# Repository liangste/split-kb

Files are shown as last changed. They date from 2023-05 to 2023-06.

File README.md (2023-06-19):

# split-kb

This repo contains the hardware design files for a 105 key QMK/VIA enabled split keyboard. The design is inspired by [Keebio Sinc](https://keeb.io/collections/sinc) and [Split111](https://geekhack.org/index.php?topic=103449.0). Unlike Sinc, this keyboard contains a Southpaw numpad, and unlike Split111, the design of this keyboard is open-sourced.

The PCB is designed using KiCAD. Case files for a stacked acrylic case is designed using Shapr3D. You can find the KiCAD project in this `root` directory, DXF drawing files under `case design/v1`, and layout and VIA files in the `layout` directory.

My QMK repo's [split-kb](https://github.com/liangste/qmk_firmware/tree/split-kb) branch contains all the configuration files necessary to run QMK and VIA. This repo only contains hardware designs.

_________________

Finished keyboard with purple top layer, clear mid layers, and wrist rests made with Red Oak hardwood (stained with linseed oil).

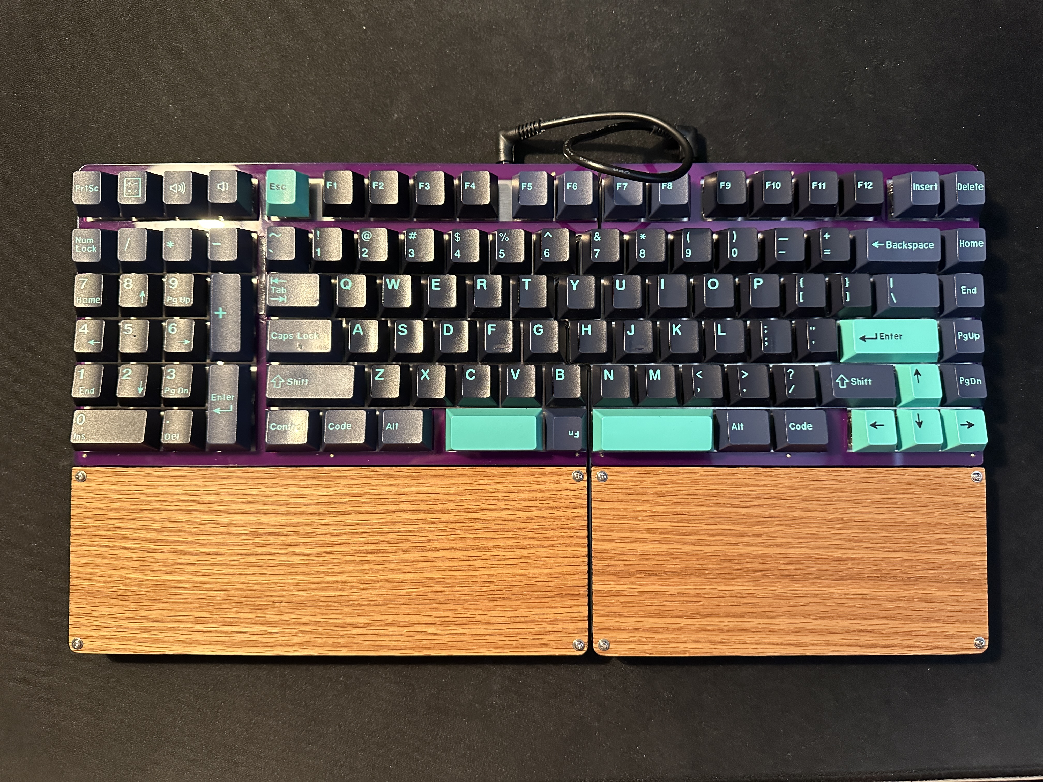
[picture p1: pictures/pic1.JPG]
top


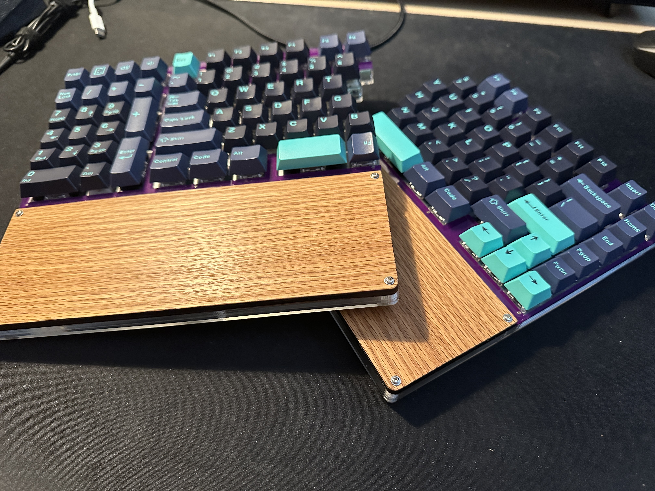
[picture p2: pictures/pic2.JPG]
split


Bottom layer showcasing a Elite-PI microcontroller and a TRRS jack for serial connection between the two halves.

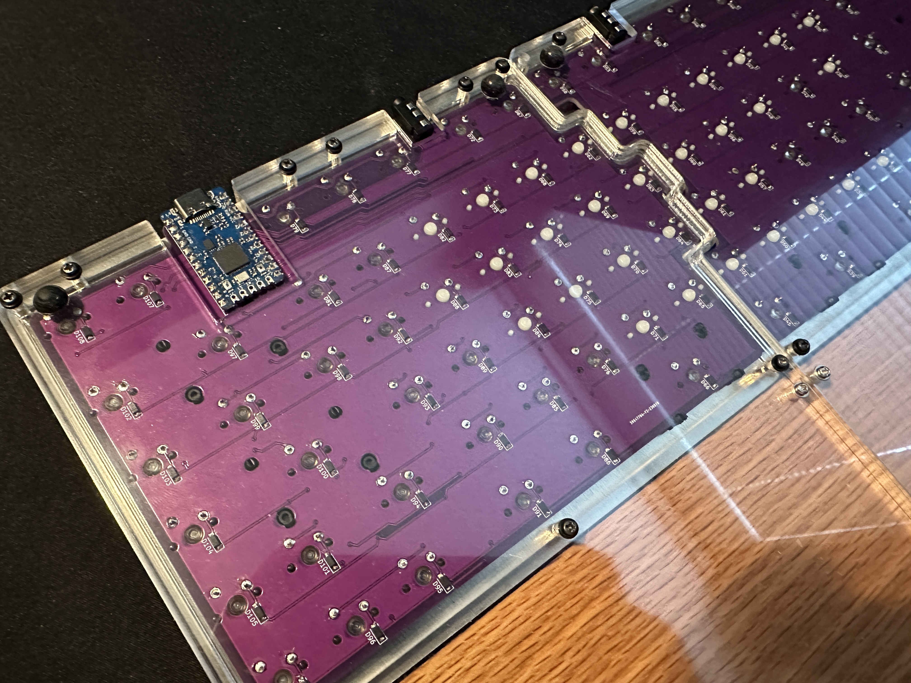
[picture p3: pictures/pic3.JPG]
bottom


A snapshot of the PCB design on KiCAD.

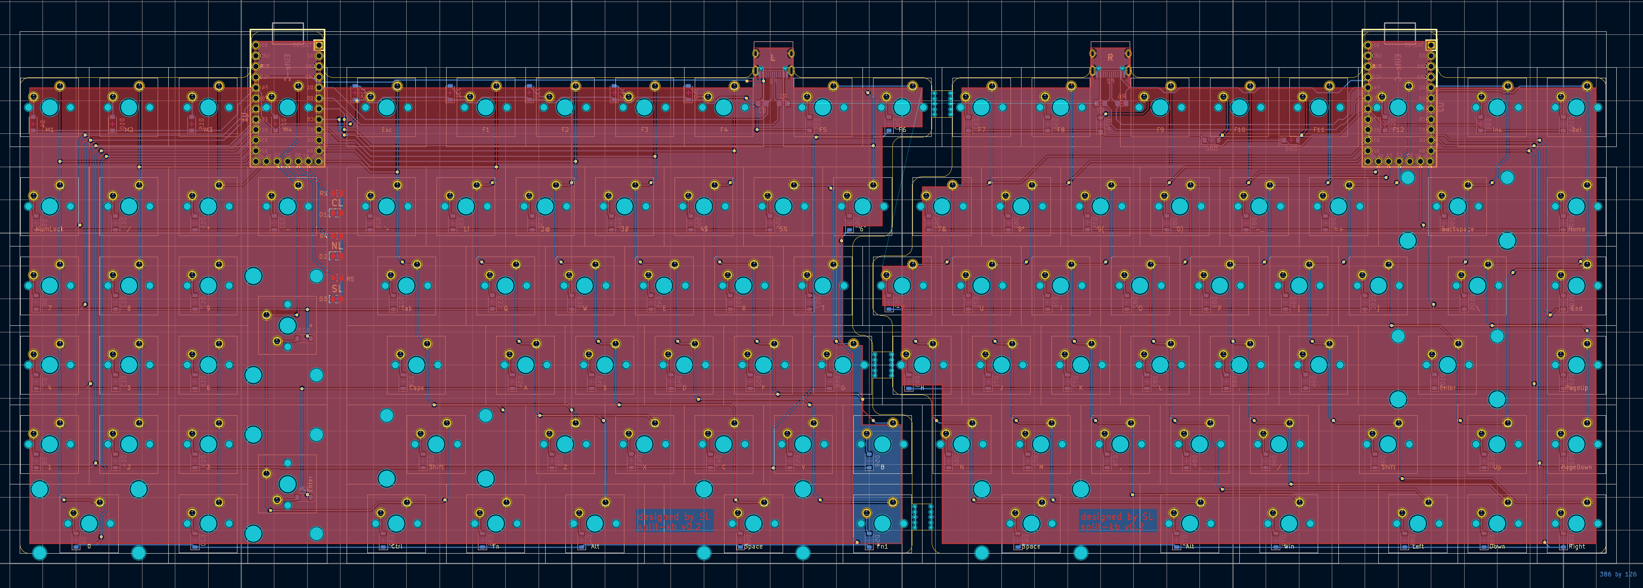
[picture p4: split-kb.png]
pcb


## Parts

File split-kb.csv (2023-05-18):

# | Reference | Qty | Value | Footprint | DNP
1 | D1, D2, D3 | 3 | LED | LED_SMD:LED_0805_2012Metric_Pad1.15x1.40mm_HandSolder
2 | D4, D5, D6, D7, D8, D9, D10, D11, D12, D13, D14, D15, D16, D17, D18, D19, D20, D21, D22, D23, D24, D25, D26, D27, D28, D29, D30, D31, D32, D33, D34, D35, D36, D37, D38, D39, D40, D41, D42, D43, D44, D45, D46, D47, D48, D49, D50, D51, D52, D53, D54, D55, D56, D57, D58, D59, D60, D61, D62, D63, D64, D65, D66, D67, D68, D69, D70, D71, D72, D73, D74, D75, D76, D77, D78, D79, D80, D81, D82, D83, D84, D85, D86, D87, D88, D89, D90, D91, D92, D93, D94, D95, D96, D97, D98, D99, D100, D101, D102, D103, D104, D105, D106, D107, D108 | 105 | D_Small | Diode_SMD:D_SOD-123
3 | MX1 | 1 | M1 | custom-footprints:Custom_SW_Cherry_MX_1.00u_PCB
4 | MX2 | 1 | NumLock | custom-footprints:Custom_SW_Cherry_MX_1.00u_PCB
5 | MX3 | 1 | 7 | custom-footprints:Custom_SW_Cherry_MX_1.00u_PCB
6 | MX4 | 1 | 4 | custom-footprints:Custom_SW_Cherry_MX_1.00u_PCB
7 | MX5 | 1 | 1 | custom-footprints:Custom_SW_Cherry_MX_1.00u_PCB
8 | MX6 | 1 | 0 | custom-footprints:Custom_SW_Cherry_MX_2.00u_PCB_stabflip
9 | MX7 | 1 | M2 | custom-footprints:Custom_SW_Cherry_MX_1.00u_PCB
10 | MX8, MX87 | 2 | / | custom-footprints:Custom_SW_Cherry_MX_1.00u_PCB
11 | MX9 | 1 | 8 | custom-footprints:Custom_SW_Cherry_MX_1.00u_PCB
12 | MX10 | 1 | 5 | custom-footprints:Custom_SW_Cherry_MX_1.00u_PCB
13 | MX11 | 1 | 2 | custom-footprints:Custom_SW_Cherry_MX_1.00u_PCB
14 | MX12 | 1 | M3 | custom-footprints:Custom_SW_Cherry_MX_1.00u_PCB
15 | MX13 | 1 | * | custom-footprints:Custom_SW_Cherry_MX_1.00u_PCB
16 | MX14 | 1 | 9 | custom-footprints:Custom_SW_Cherry_MX_1.00u_PCB
17 | MX15 | 1 | 6 | custom-footprints:Custom_SW_Cherry_MX_1.00u_PCB
18 | MX16 | 1 | 3 | custom-footprints:Custom_SW_Cherry_MX_1.00u_PCB
19 | MX17, MX81 | 2 | . | custom-footprints:Custom_SW_Cherry_MX_1.00u_PCB
20 | MX18 | 1 | M4 | custom-footprints:Custom_SW_Cherry_MX_1.00u_PCB
21 | MX19 | 1 | - | custom-footprints:Custom_SW_Cherry_MX_1.00u_PCB
22 | MX20 | 1 | + | custom-footprints:Custom_SW_Cherry_MX_2.00u_PCB_stabflip
23 | MX21 | 1 | Enter | custom-footprints:Custom_SW_Cherry_MX_2.00u_PCB_stabflip
24 | MX22 | 1 | Esc | custom-footprints:Custom_SW_Cherry_MX_1.00u_PCB
25 | MX23 | 1 | `~ | custom-footprints:Custom_SW_Cherry_MX_1.00u_PCB
26 | MX24 | 1 | Tab | custom-footprints:Custom_SW_Cherry_MX_1.50u_PCB
27 | MX25 | 1 | Caps | custom-footprints:Custom_SW_Cherry_MX_1.75u_PCB
28 | MX26 | 1 | Shift | custom-footprints:Custom_SW_Cherry_MX_2.25u_PCB
29 | MX27 | 1 | Ctrl | custom-footprints:Custom_SW_Cherry_MX_1.25u_PCB
30 | MX28 | 1 | F1 | custom-footprints:Custom_SW_Cherry_MX_1.00u_PCB
31 | MX29 | 1 | 1! | custom-footprints:Custom_SW_Cherry_MX_1.00u_PCB
32 | MX30 | 1 | Q | custom-footprints:Custom_SW_Cherry_MX_1.00u_PCB
33 | MX31 | 1 | A | custom-footprints:Custom_SW_Cherry_MX_1.00u_PCB
34 | MX32 | 1 | Z | custom-footprints:Custom_SW_Cherry_MX_1.00u_PCB
35 | MX33 | 1 | Fn | custom-footprints:Custom_SW_Cherry_MX_1.25u_PCB
36 | MX34 | 1 | F2 | custom-footprints:Custom_SW_Cherry_MX_1.00u_PCB
37 | MX35 | 1 | 2@ | custom-footprints:Custom_SW_Cherry_MX_1.00u_PCB
38 | MX36 | 1 | W | custom-footprints:Custom_SW_Cherry_MX_1.00u_PCB
39 | MX37 | 1 | S | custom-footprints:Custom_SW_Cherry_MX_1.00u_PCB
40 | MX38 | 1 | X | custom-footprints:Custom_SW_Cherry_MX_1.00u_PCB
41 | MX39, MX70 | 2 | Alt | custom-footprints:Custom_SW_Cherry_MX_1.25u_PCB
42 | MX40 | 1 | F3 | custom-footprints:Custom_SW_Cherry_MX_1.00u_PCB
43 | MX41 | 1 | 3# | custom-footprints:Custom_SW_Cherry_MX_1.00u_PCB
44 | MX42 | 1 | E | custom-footprints:Custom_SW_Cherry_MX_1.00u_PCB
45 | MX43 | 1 | D | custom-footprints:Custom_SW_Cherry_MX_1.00u_PCB
46 | MX44 | 1 | C | custom-footprints:Custom_SW_Cherry_MX_1.00u_PCB
47 | MX45 | 1 | Space | custom-footprints:Custom_SW_Cherry_MX_2.25u_PCB_stabflip
48 | MX46 | 1 | F4 | custom-footprints:Custom_SW_Cherry_MX_1.00u_PCB
49 | MX47 | 1 | 4$ | custom-footprints:Custom_SW_Cherry_MX_1.00u_PCB
50 | MX48 | 1 | R | custom-footprints:Custom_SW_Cherry_MX_1.00u_PCB
51 | MX49 | 1 | F | custom-footprints:Custom_SW_Cherry_MX_1.00u_PCB
52 | MX50 | 1 | V | custom-footprints:Custom_SW_Cherry_MX_1.00u_PCB
53 | MX51 | 1 | Fn1 | custom-footprints:Custom_SW_Cherry_MX_1.00u_PCB
54 | MX52 | 1 | F5 | custom-footprints:Custom_SW_Cherry_MX_1.00u_PCB
55 | MX53 | 1 | 5% | custom-footprints:Custom_SW_Cherry_MX_1.00u_PCB
56 | MX54 | 1 | T | custom-footprints:Custom_SW_Cherry_MX_1.00u_PCB
57 | MX55 | 1 | G | custom-footprints:Custom_SW_Cherry_MX_1.00u_PCB
58 | MX56 | 1 | B | custom-footprints:Custom_SW_Cherry_MX_1.00u_PCB
59 | MX57 | 1 | F6 | custom-footprints:Custom_SW_Cherry_MX_1.00u_PCB
60 | MX58 | 1 | 6^ | custom-footprints:Custom_SW_Cherry_MX_1.00u_PCB
61 | MX59 | 1 | F7 | custom-footprints:Custom_SW_Cherry_MX_1.00u_PCB
62 | MX60 | 1 | 7& | custom-footprints:Custom_SW_Cherry_MX_1.00u_PCB
63 | MX61 | 1 | Y | custom-footprints:Custom_SW_Cherry_MX_1.00u_PCB
64 | MX62 | 1 | H | custom-footprints:Custom_SW_Cherry_MX_1.00u_PCB
65 | MX63 | 1 | N | custom-footprints:Custom_SW_Cherry_MX_1.00u_PCB
66 | MX64 | 1 | Space | custom-footprints:Custom_SW_Cherry_MX_2.75u_PCB_stabflip
67 | MX65 | 1 | F8 | custom-footprints:Custom_SW_Cherry_MX_1.00u_PCB
68 | MX66 | 1 | 8* | custom-footprints:Custom_SW_Cherry_MX_1.00u_PCB
69 | MX67 | 1 | U | custom-footprints:Custom_SW_Cherry_MX_1.00u_PCB
70 | MX68 | 1 | J | custom-footprints:Custom_SW_Cherry_MX_1.00u_PCB
71 | MX69 | 1 | M | custom-footprints:Custom_SW_Cherry_MX_1.00u_PCB
72 | MX71 | 1 | F9 | custom-footprints:Custom_SW_Cherry_MX_1.00u_PCB
73 | MX72 | 1 | 9( | custom-footprints:Custom_SW_Cherry_MX_1.00u_PCB
74 | MX73 | 1 | I | custom-footprints:Custom_SW_Cherry_MX_1.00u_PCB
75 | MX74 | 1 | K | custom-footprints:Custom_SW_Cherry_MX_1.00u_PCB
76 | MX75 | 1 | , | custom-footprints:Custom_SW_Cherry_MX_1.00u_PCB
77 | MX76 | 1 | Win | custom-footprints:Custom_SW_Cherry_MX_1.25u_PCB
78 | MX77 | 1 | F10 | custom-footprints:Custom_SW_Cherry_MX_1.00u_PCB
79 | MX78 | 1 | 0) | custom-footprints:Custom_SW_Cherry_MX_1.00u_PCB
80 | MX79 | 1 | O | custom-footprints:Custom_SW_Cherry_MX_1.00u_PCB
81 | MX80 | 1 | L | custom-footprints:Custom_SW_Cherry_MX_1.00u_PCB
82 | MX82 | 1 | Left | custom-footprints:Custom_SW_Cherry_MX_1.00u_PCB
83 | MX83 | 1 | F11 | custom-footprints:Custom_SW_Cherry_MX_1.00u_PCB
84 | MX84 | 1 | -_ | custom-footprints:Custom_SW_Cherry_MX_1.00u_PCB
85 | MX85 | 1 | P | custom-footprints:Custom_SW_Cherry_MX_1.00u_PCB
86 | MX86 | 1 | ; | custom-footprints:Custom_SW_Cherry_MX_1.00u_PCB
87 | MX88 | 1 | Down | custom-footprints:Custom_SW_Cherry_MX_1.00u_PCB
88 | MX89 | 1 | F12 | custom-footprints:Custom_SW_Cherry_MX_1.00u_PCB
89 | MX90 | 1 | =+ | custom-footprints:Custom_SW_Cherry_MX_1.00u_PCB
90 | MX91 | 1 | [ | custom-footprints:Custom_SW_Cherry_MX_1.00u_PCB
91 | MX92 | 1 | ' | custom-footprints:Custom_SW_Cherry_MX_1.00u_PCB
92 | MX93 | 1 | Shift | custom-footprints:Custom_SW_Cherry_MX_1.75u_PCB
93 | MX94 | 1 | Right | custom-footprints:Custom_SW_Cherry_MX_1.00u_PCB
94 | MX95 | 1 | Ins | custom-footprints:Custom_SW_Cherry_MX_1.00u_PCB
95 | MX96 | 1 | Backspace | custom-footprints:Custom_SW_Cherry_MX_2.00u_PCB
96 | MX97 | 1 | ] | custom-footprints:Custom_SW_Cherry_MX_1.00u_PCB
97 | MX98 | 1 | Enter | custom-footprints:Custom_SW_Cherry_MX_2.25u_PCB
98 | MX99 | 1 | Up | custom-footprints:Custom_SW_Cherry_MX_1.00u_PCB
99 | MX100 | 1 | Del | custom-footprints:Custom_SW_Cherry_MX_1.00u_PCB
100 | MX101 | 1 | Home | custom-footprints:Custom_SW_Cherry_MX_1.00u_PCB
101 | MX102 | 1 | \ | custom-footprints:Custom_SW_Cherry_MX_1.50u_PCB
102 | MX103 | 1 | PageUp | custom-footprints:Custom_SW_Cherry_MX_1.00u_PCB
103 | MX104 | 1 | PageDown | custom-footprints:Custom_SW_Cherry_MX_1.00u_PCB
104 | MX105 | 1 | End | custom-footprints:Custom_SW_Cherry_MX_1.00u_PCB
105 | P1, P2 | 2 | I2C/USB-C | Connector_USB:USB_C_Receptacle_HRO_TYPE-C-31-M-12
106 | R1, R4, R5 | 3 | 2.2k | Resistor_SMD:R_0805_2012Metric_Pad1.20x1.40mm_HandSolder
107 | R2, R3, R6, R7 | 4 | 2.2K | Resistor_SMD:R_0805_2012Metric_Pad1.20x1.40mm_HandSolder
108 | U1, U2 | 2 | Elite-C | Keebio-Parts:Elite-C

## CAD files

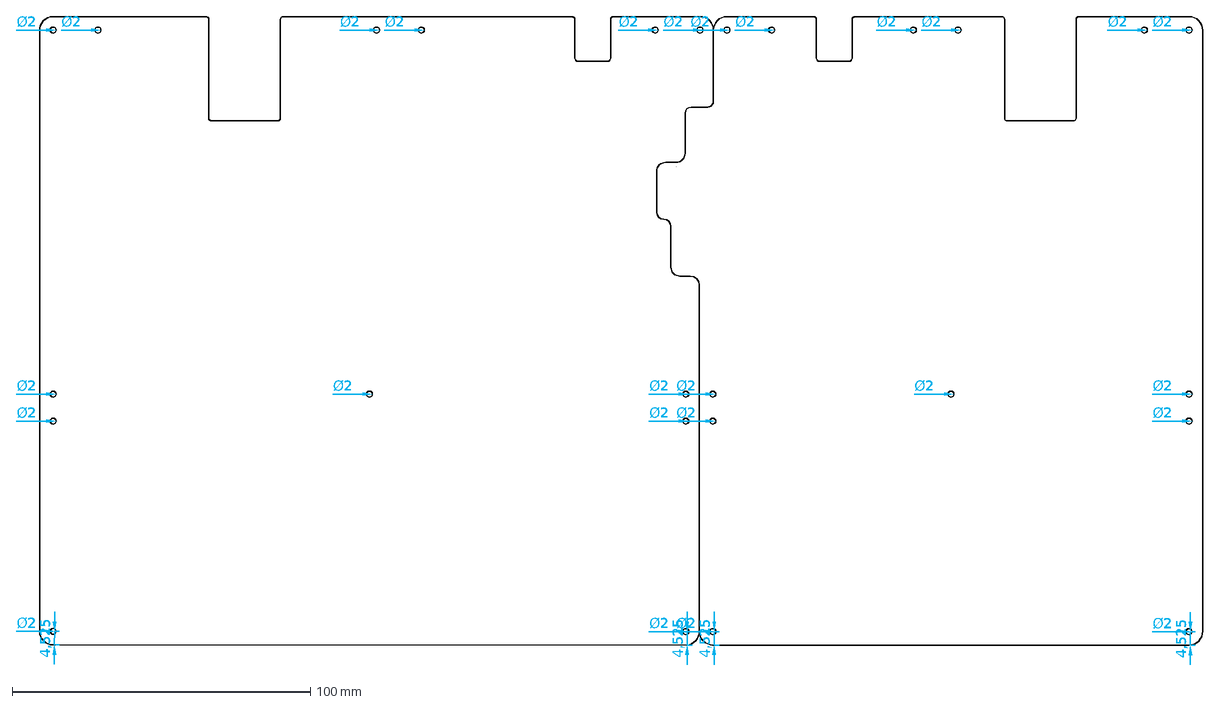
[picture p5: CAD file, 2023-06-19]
case design/v1/combined baseplates v1.dxf
4,525
Ø2

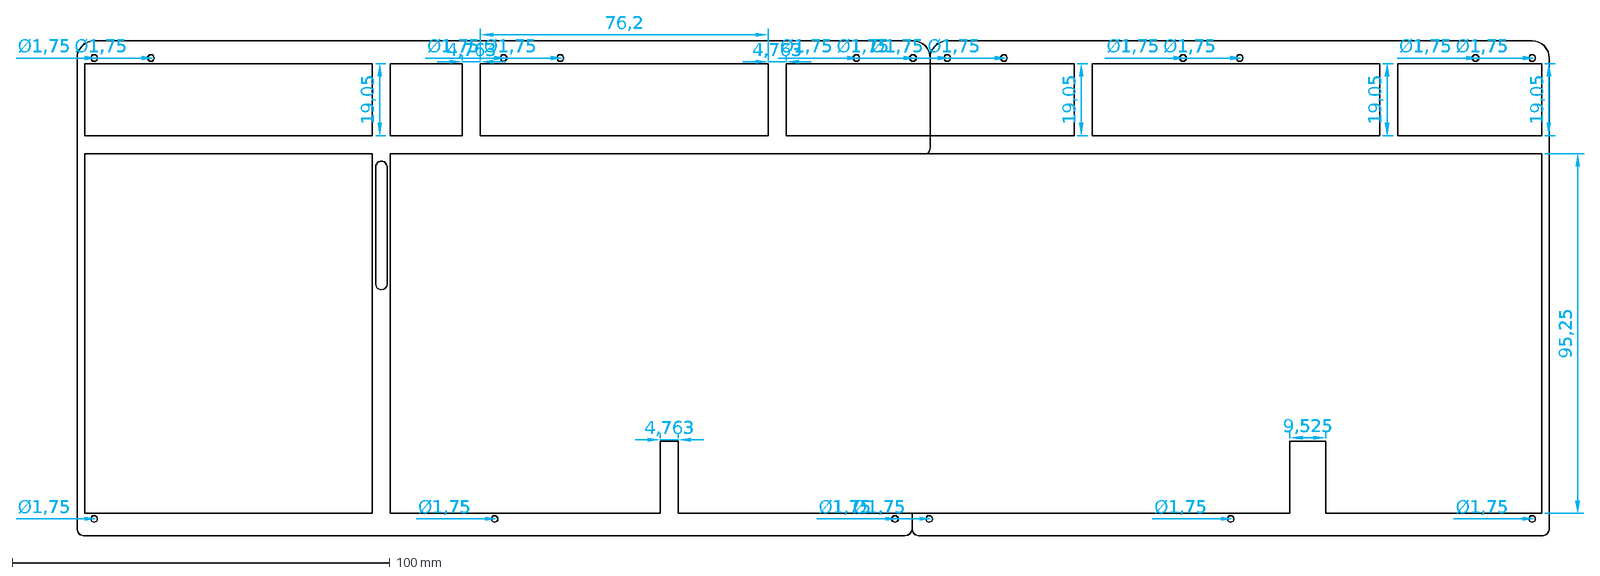
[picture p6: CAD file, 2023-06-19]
case design/v1/combined topplates v1.1.dxf
19,05
95,25
4,763
76,2
9,525
Ø1,75

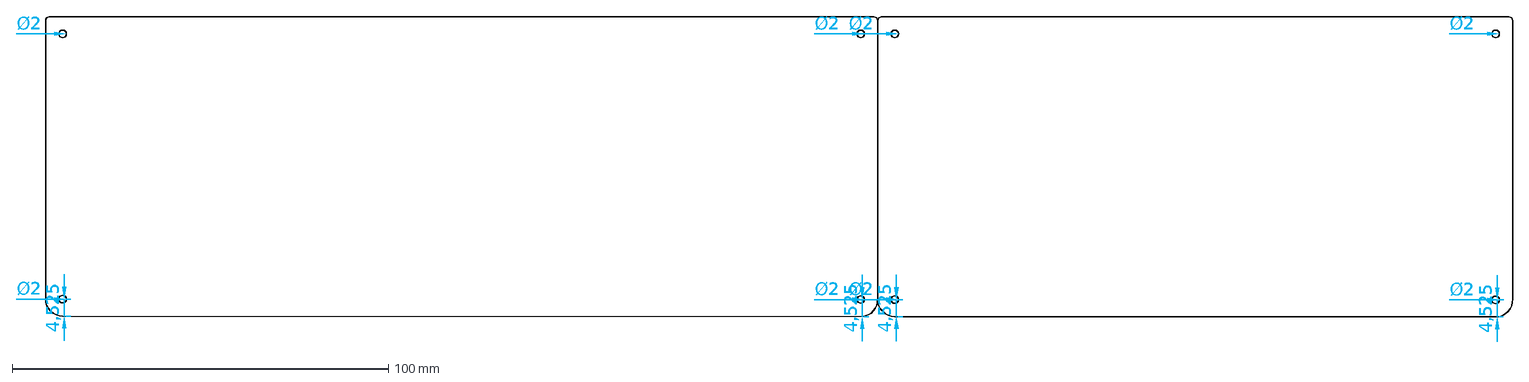
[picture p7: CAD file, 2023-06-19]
case design/v1/combined wrist rests v1.dxf
4,525
Ø2

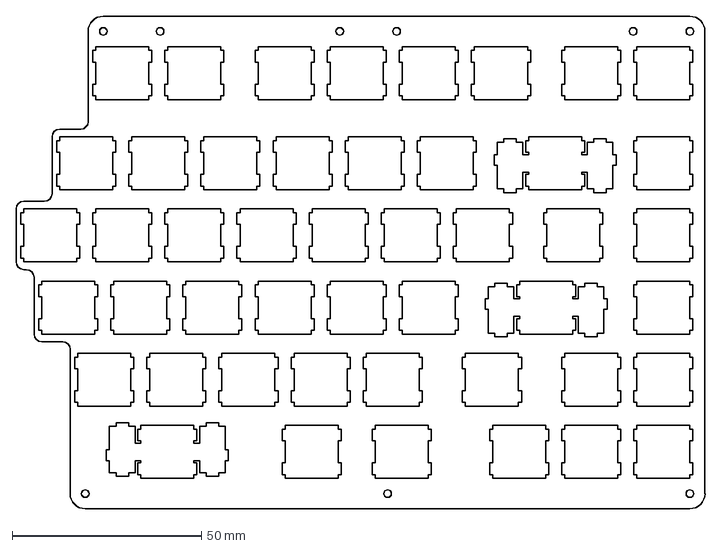
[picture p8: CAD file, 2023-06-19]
case design/v1/right switchplate v1.dxf
181.9 x 130.0 mm

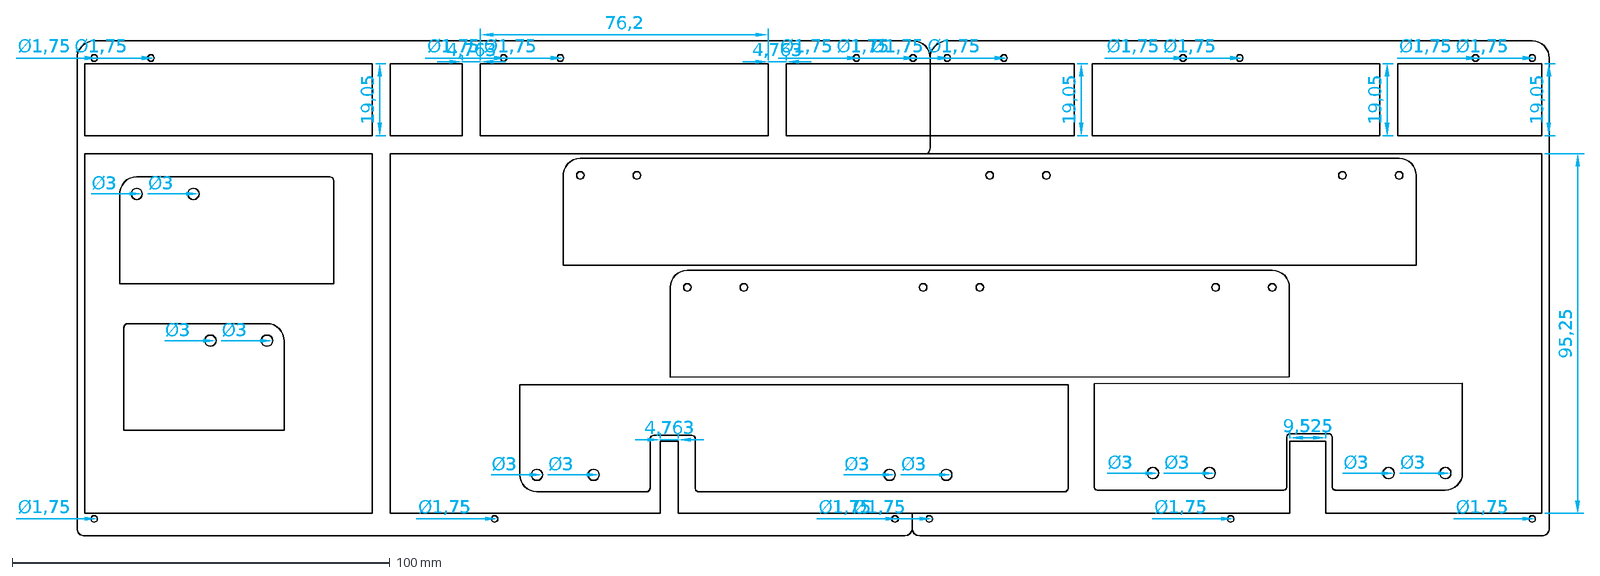
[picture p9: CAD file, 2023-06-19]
case design/v1/combined topplates v1.1 w_ feet.dxf
19,05
95,25
4,763
76,2
9,525
Ø3
Ø1,75

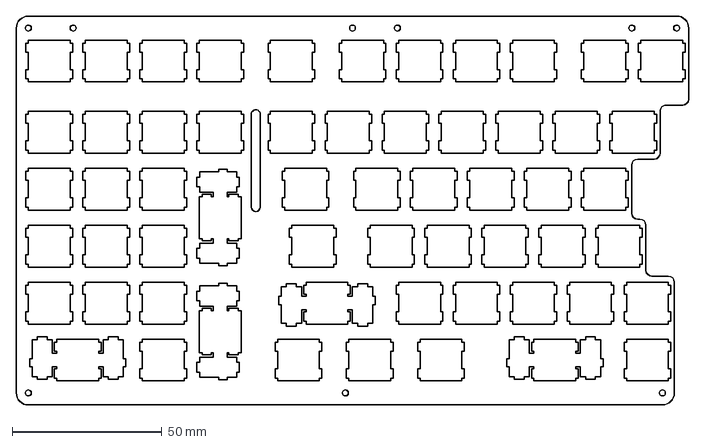
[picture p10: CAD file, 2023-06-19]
case design/v1/left switchplate v1.dxf
224.8 x 130.0 mm

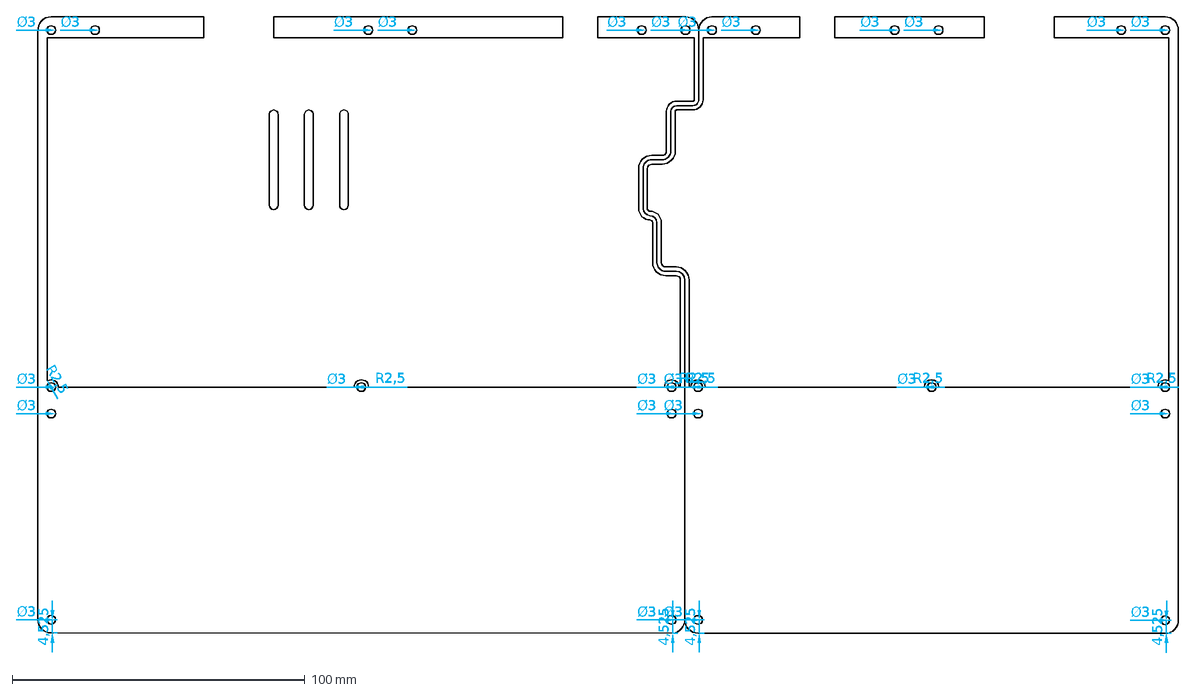
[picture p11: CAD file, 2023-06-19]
case design/v1/combined midplates v1.dxf
4,525
R2,5
Ø3

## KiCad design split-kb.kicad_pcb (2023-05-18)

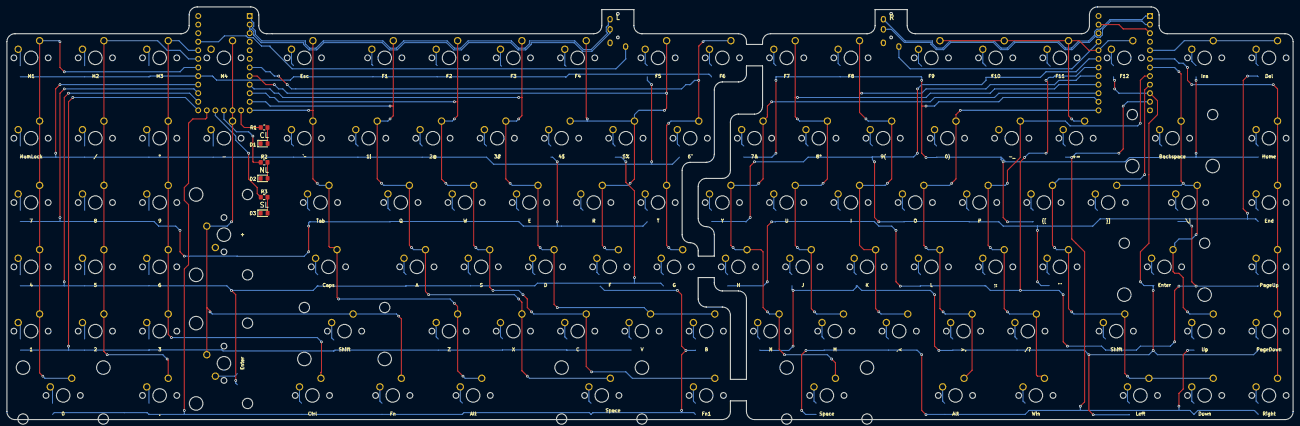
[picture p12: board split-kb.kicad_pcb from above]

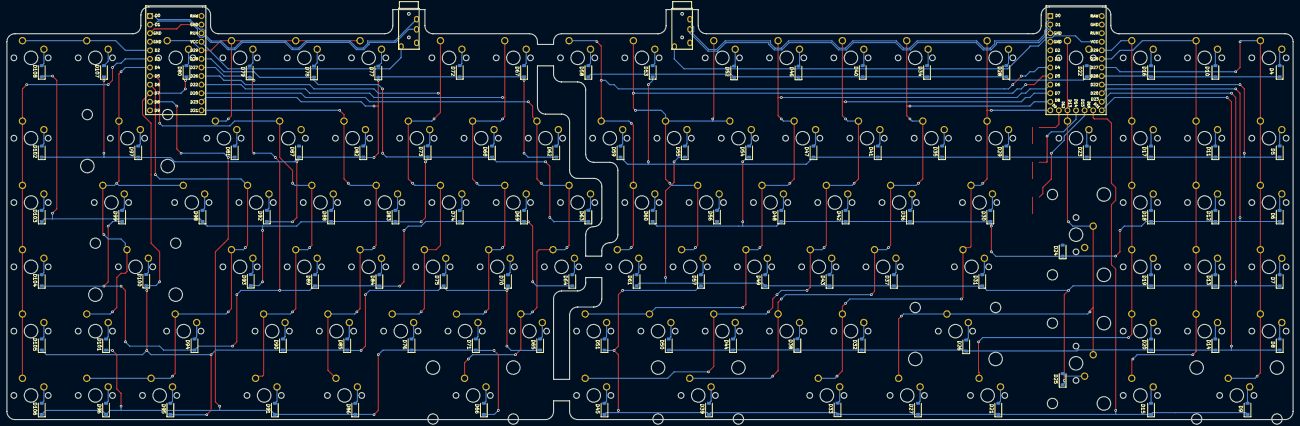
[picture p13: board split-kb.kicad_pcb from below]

Board: 2 copper layers, 381.0 x 122.2 mm, 220 parts (109 on the bottom side), 148 nets.

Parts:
D1, D2, D3: LED; LED_0805_2012Metric_Pad1.15x1.40mm_HandSolder
D4, D5, D6, D7, D8, D9, D10, D11, D12, D13, D14, D15, D16, D17, D18, D19, D20, D21, D22, D23, D24, D25, D26, D27, D28, D29, D30, D31, D32, D33, D34, D35, D36, D37, D38, D39, D40, D41, D42, D43, D44, D45, D46, D47, D48, D49, D50, D51, D52, D53, D54, D55, D56, D57, D58, D59, D60, D61, D62, D63, D64, D65, D66, D67, D68, D69, D70, D71, D72, D73, D74, D75, D76, D77, D78, D79, D80, D81, D82, D83, D84, D85, D86, D87, D88, D89, D90, D91, D92, D93, D94, D95, D96, D97, D98, D99, D100, D101, D102, D103, D104, D105, D106, D107, D108: D_Small; D_SOD-123
MX1: M1; Custom_SW_Cherry_MX_1.00u_PCB
MX2: NumLock; Custom_SW_Cherry_MX_1.00u_PCB
MX3: 7; Custom_SW_Cherry_MX_1.00u_PCB
MX4: 4; Custom_SW_Cherry_MX_1.00u_PCB
MX5: 1; Custom_SW_Cherry_MX_1.00u_PCB
MX6: 0; Custom_SW_Cherry_MX_2.00u_PCB_stabflip
MX7: M2; Custom_SW_Cherry_MX_1.00u_PCB
MX8: /; Custom_SW_Cherry_MX_1.00u_PCB
MX9: 8; Custom_SW_Cherry_MX_1.00u_PCB
MX10: 5; Custom_SW_Cherry_MX_1.00u_PCB
MX11: 2; Custom_SW_Cherry_MX_1.00u_PCB
MX12: .; Custom_SW_Cherry_MX_1.00u_PCB
MX13: M3; Custom_SW_Cherry_MX_1.00u_PCB
MX14: *; Custom_SW_Cherry_MX_1.00u_PCB
MX15: 9; Custom_SW_Cherry_MX_1.00u_PCB
MX16: 6; Custom_SW_Cherry_MX_1.00u_PCB
MX17: 3; Custom_SW_Cherry_MX_1.00u_PCB
MX18: Ctrl; Custom_SW_Cherry_MX_1.25u_PCB
MX19: M4; Custom_SW_Cherry_MX_1.00u_PCB
MX20: -; Custom_SW_Cherry_MX_1.00u_PCB
MX21: +; Custom_SW_Cherry_MX_2.00u_PCB_stabflip
MX22: Enter; Custom_SW_Cherry_MX_2.00u_PCB_stabflip
MX23: Shift; Custom_SW_Cherry_MX_2.25u_PCB
MX24: Fn; Custom_SW_Cherry_MX_1.25u_PCB
MX25: Esc; Custom_SW_Cherry_MX_1.00u_PCB
MX26: `~; Custom_SW_Cherry_MX_1.00u_PCB
MX27: Tab; Custom_SW_Cherry_MX_1.50u_PCB
MX28: Caps; Custom_SW_Cherry_MX_1.75u_PCB
MX29: Z; Custom_SW_Cherry_MX_1.00u_PCB
MX30, MX83: Alt; Custom_SW_Cherry_MX_1.25u_PCB
MX31: F1; Custom_SW_Cherry_MX_1.00u_PCB
MX32: 1!; Custom_SW_Cherry_MX_1.00u_PCB
MX33: Q; Custom_SW_Cherry_MX_1.00u_PCB
MX34: A; Custom_SW_Cherry_MX_1.00u_PCB
MX35: X; Custom_SW_Cherry_MX_1.00u_PCB
MX36: Space; Custom_SW_Cherry_MX_2.25u_PCB_stabflip
MX37: F2; Custom_SW_Cherry_MX_1.00u_PCB
MX38: 2@; Custom_SW_Cherry_MX_1.00u_PCB
MX39: W; Custom_SW_Cherry_MX_1.00u_PCB
MX40: S; Custom_SW_Cherry_MX_1.00u_PCB
MX41: C; Custom_SW_Cherry_MX_1.00u_PCB
MX42: Fn1; Custom_SW_Cherry_MX_1.00u_PCB
MX43: F3; Custom_SW_Cherry_MX_1.00u_PCB
MX44: 3#; Custom_SW_Cherry_MX_1.00u_PCB
MX45: E; Custom_SW_Cherry_MX_1.00u_PCB
MX46: D; Custom_SW_Cherry_MX_1.00u_PCB
MX47: V; Custom_SW_Cherry_MX_1.00u_PCB
MX48: B; Custom_SW_Cherry_MX_1.00u_PCB
MX49: F4; Custom_SW_Cherry_MX_1.00u_PCB
MX50: F5; Custom_SW_Cherry_MX_1.00u_PCB
MX51: 4$; Custom_SW_Cherry_MX_1.00u_PCB
MX52: 5%; Custom_SW_Cherry_MX_1.00u_PCB
MX53: R; Custom_SW_Cherry_MX_1.00u_PCB
MX54: F; Custom_SW_Cherry_MX_1.00u_PCB
MX55: F6; Custom_SW_Cherry_MX_1.00u_PCB
MX56: 6^; Custom_SW_Cherry_MX_1.00u_PCB
MX57: T; Custom_SW_Cherry_MX_1.00u_PCB
MX58: G; Custom_SW_Cherry_MX_1.00u_PCB
MX59: 7&; Custom_SW_Cherry_MX_1.00u_PCB
MX60: Y; Custom_SW_Cherry_MX_1.00u_PCB
MX61: H; Custom_SW_Cherry_MX_1.00u_PCB
MX62: N; Custom_SW_Cherry_MX_1.00u_PCB
MX63: Space; Custom_SW_Cherry_MX_2.75u_PCB_stabflip
MX64: F7; Custom_SW_Cherry_MX_1.00u_PCB
MX65: 8*; Custom_SW_Cherry_MX_1.00u_PCB
MX66: U; Custom_SW_Cherry_MX_1.00u_PCB
MX67: J; Custom_SW_Cherry_MX_1.00u_PCB
MX68: M; Custom_SW_Cherry_MX_1.00u_PCB
MX69: F8; Custom_SW_Cherry_MX_1.00u_PCB
MX70: 9(; Custom_SW_Cherry_MX_1.00u_PCB
MX71: I; Custom_SW_Cherry_MX_1.00u_PCB
MX72: K; Custom_SW_Cherry_MX_1.00u_PCB
MX73: ,<; Custom_SW_Cherry_MX_1.00u_PCB
MX74: F9; Custom_SW_Cherry_MX_1.00u_PCB
MX75: F10; Custom_SW_Cherry_MX_1.00u_PCB
MX76: F11; Custom_SW_Cherry_MX_1.00u_PCB
MX77: F12; Custom_SW_Cherry_MX_1.00u_PCB
MX78: +=; Custom_SW_Cherry_MX_1.00u_PCB
MX79: 0); Custom_SW_Cherry_MX_1.00u_PCB
MX80: O; Custom_SW_Cherry_MX_1.00u_PCB
MX81: L; Custom_SW_Cherry_MX_1.00u_PCB
MX82: >.; Custom_SW_Cherry_MX_1.00u_PCB
MX84: -_; Custom_SW_Cherry_MX_1.00u_PCB
MX85: P; Custom_SW_Cherry_MX_1.00u_PCB
MX86: ;:; Custom_SW_Cherry_MX_1.00u_PCB
MX87: /?; Custom_SW_Cherry_MX_1.00u_PCB
MX88: Win; Custom_SW_Cherry_MX_1.25u_PCB
MX89: {[; Custom_SW_Cherry_MX_1.00u_PCB
MX90: "'; Custom_SW_Cherry_MX_1.00u_PCB
MX91: Shift; Custom_SW_Cherry_MX_1.75u_PCB
MX92: Left; Custom_SW_Cherry_MX_1.00u_PCB
MX93: Down; Custom_SW_Cherry_MX_1.00u_PCB
MX94: Backspace; Custom_SW_Cherry_MX_2.00u_PCB
MX95: }]; Custom_SW_Cherry_MX_1.00u_PCB
MX96: \|; Custom_SW_Cherry_MX_1.50u_PCB
MX97: Enter; Custom_SW_Cherry_MX_2.25u_PCB
MX98: Up; Custom_SW_Cherry_MX_1.00u_PCB
MX99: Home; Custom_SW_Cherry_MX_1.00u_PCB
MX100: End; Custom_SW_Cherry_MX_1.00u_PCB
MX101: PageUp; Custom_SW_Cherry_MX_1.00u_PCB
MX102: PageDown; Custom_SW_Cherry_MX_1.00u_PCB
MX103: Right; Custom_SW_Cherry_MX_1.00u_PCB
MX104: Ins; Custom_SW_Cherry_MX_1.00u_PCB
MX105: Del; Custom_SW_Cherry_MX_1.00u_PCB
R1, R2, R3: 2.2k; R_0805_2012Metric_Pad1.20x1.40mm_HandSolder
U1, U3: TRRS; TRRS-PJ-320A
U2: Elite-PI
U4: Elite-PI; Elite-PI_24pin

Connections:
+3.3V: U1.1 (SLEEVE), U2.21 (VCC), U3.1 (SLEEVE), U4.21 (VCC)
/left_pcb/col0: MX1.1 (COL), MX2.1 (COL), MX3.1 (COL), MX4.1 (COL), MX5.1 (COL), MX6.1 (COL), U2.18 (D27)
/left_pcb/col1: MX7.1 (COL), MX8.1 (COL), MX9.1 (COL), MX10.1 (COL), MX11.1 (COL), MX12.1 (COL), U2.19 (D28)
/left_pcb/col2: MX13.1 (COL), MX14.1 (COL), MX15.1 (COL), MX16.1 (COL), MX17.1 (COL), MX18.1 (COL), U2.20 (D29)
/left_pcb/col3: MX19.1 (COL), MX20.1 (COL), MX21.1 (COL), MX22.1 (COL), MX23.1 (COL), MX24.1 (COL), U2.26 (D13)
/left_pcb/col4: MX25.1 (COL), MX26.1 (COL), MX27.1 (COL), MX28.1 (COL), MX29.1 (COL), MX30.1 (COL), U2.12 (D9)
/left_pcb/col5: MX31.1 (COL), MX32.1 (COL), MX33.1 (COL), MX34.1 (COL), MX35.1 (COL), MX36.1 (COL), U2.11 (D8)
/left_pcb/col6: MX37.1 (COL), MX38.1 (COL), MX39.1 (COL), MX40.1 (COL), MX41.1 (COL), MX42.1 (COL), U2.10 (D7)
/left_pcb/col7: MX43.1 (COL), MX44.1 (COL), MX45.1 (COL), MX46.1 (COL), MX47.1 (COL), MX48.1 (COL), U2.9 (D6)
/left_pcb/col8: MX49.1 (COL), MX50.1 (COL), MX51.1 (COL), MX52.1 (COL), MX53.1 (COL), MX54.1 (COL), U2.8 (D5)
/left_pcb/col9: MX55.1 (COL), MX56.1 (COL), MX57.1 (COL), MX58.1 (COL), U2.7 (D4)
/left_pcb/led0: R1.1, U2.25 (D12)
/left_pcb/led1: R2.1, U2.27 (D14)
/left_pcb/led2: R3.1, U2.28 (D15)
/left_pcb/row0: D4.1 (K), D10.1 (K), D16.1 (K), D22.1 (K), D28.1 (K), D34.1 (K), D40.1 (K), D46.1 (K), D52.1 (K), D58.1 (K), U2.17 (D26)
/left_pcb/row1: D5.1 (K), D11.1 (K), D17.1 (K), D23.1 (K), D29.1 (K), D35.1 (K), D41.1 (K), D47.1 (K), D53.1 (K), D59.1 (K), U2.16 (D22)
/left_pcb/row2: D6.1 (K), D12.1 (K), D18.1 (K), D24.1 (K), D30.1 (K), D36.1 (K), D42.1 (K), D48.1 (K), D54.1 (K), D60.1 (K), U2.15 (D20)
/left_pcb/row3: D7.1 (K), D13.1 (K), D19.1 (K), D25.1 (K), D31.1 (K), D37.1 (K), D43.1 (K), D49.1 (K), D55.1 (K), D61.1 (K), U2.14 (D23)
/left_pcb/row4: D8.1 (K), D14.1 (K), D20.1 (K), D26.1 (K), D32.1 (K), D38.1 (K), D44.1 (K), D50.1 (K), D56.1 (K), U2.13 (D21)
/left_pcb/row5: D9.1 (K), D15.1 (K), D21.1 (K), D27.1 (K), D33.1 (K), D39.1 (K), D45.1 (K), D51.1 (K), D57.1 (K), U2.29 (D16)
/left_pcb/serial+: U1.4 (RING2), U2.1 (D0)
/left_pcb/serial-: U1.3 (RING1), U2.2 (D1)
/right_pcb/col0: MX59.1 (COL), MX60.1 (COL), MX61.1 (COL), MX62.1 (COL), MX63.1 (COL), U4.15 (D20)
/right_pcb/col1: MX64.1 (COL), MX65.1 (COL), MX66.1 (COL), MX67.1 (COL), MX68.1 (COL), U4.16 (D22)
/right_pcb/col2: MX69.1 (COL), MX70.1 (COL), MX71.1 (COL), MX72.1 (COL), MX73.1 (COL), U4.17 (D26)
/right_pcb/col3: MX74.1 (COL), MX75.1 (COL), MX76.1 (COL), MX77.1 (COL), MX78.1 (COL), U4.20 (D29)
/right_pcb/col4: MX79.1 (COL), MX80.1 (COL), MX81.1 (COL), MX82.1 (COL), MX83.1 (COL), U4.13 (D21)
/right_pcb/col5: MX84.1 (COL), MX85.1 (COL), MX86.1 (COL), MX87.1 (COL), MX88.1 (COL), U4.8 (D5)
/right_pcb/col6: MX89.1 (COL), MX90.1 (COL), MX91.1 (COL), MX92.1 (COL), MX93.1 (COL), U4.9 (D6)
/right_pcb/col7: MX94.1 (COL), MX95.1 (COL), MX96.1 (COL), MX97.1 (COL), MX98.1 (COL), U4.7 (D4)
/right_pcb/col8: MX99.1 (COL), MX100.1 (COL), MX101.1 (COL), MX102.1 (COL), MX103.1 (COL), U4.6 (D3)
/right_pcb/col9: MX104.1 (COL), MX105.1 (COL), U4.5 (D2)
/right_pcb/row0: D62.1 (K), D67.1 (K), D72.1 (K), D77.1 (K), D82.1 (K), D87.1 (K), D92.1 (K), D97.1 (K), D102.1 (K), D107.1 (K), U4.14 (D23)
/right_pcb/row1: D63.1 (K), D68.1 (K), D73.1 (K), D78.1 (K), D83.1 (K), D88.1 (K), D93.1 (K), D98.1 (K), D103.1 (K), D108.1 (K), U4.19 (D28)
/right_pcb/row2: D64.1 (K), D69.1 (K), D74.1 (K), D79.1 (K), D84.1 (K), D89.1 (K), D94.1 (K), D99.1 (K), D104.1 (K), U4.18 (D27)
/right_pcb/row3: D65.1 (K), D70.1 (K), D75.1 (K), D80.1 (K), D85.1 (K), D90.1 (K), D95.1 (K), D100.1 (K), D105.1 (K), U4.10 (D7)
/right_pcb/row4: D66.1 (K), D71.1 (K), D76.1 (K), D81.1 (K), D86.1 (K), D91.1 (K), D96.1 (K), D101.1 (K), D106.1 (K), U4.11 (D8)
/right_pcb/serial+: U3.4 (RING2), U4.1 (D0)
/right_pcb/serial-: U3.3 (RING1), U4.2 (D1)
GND: D1.1 (K), D2.1 (K), D3.1 (K), U1.2 (TIP), U2.3 (GND), U2.4 (GND), U2.23 (GND), U3.2 (TIP), U4.3 (GND), U4.4 (GND), U4.23 (GND)
unnamed: D1.2 (A), R1.2
unnamed: D2.2 (A), R2.2
unnamed: D3.2 (A), R3.2
unnamed: D4.2 (A), MX1.2 (ROW)
unnamed: D5.2 (A), MX2.2 (ROW)
unnamed: D6.2 (A), MX3.2 (ROW)
unnamed: D7.2 (A), MX4.2 (ROW)
unnamed: D8.2 (A), MX5.2 (ROW)
unnamed: D9.2 (A), MX6.2 (ROW)
unnamed: D10.2 (A), MX7.2 (ROW)
unnamed: D11.2 (A), MX8.2 (ROW)
unnamed: D12.2 (A), MX9.2 (ROW)
unnamed: D13.2 (A), MX10.2 (ROW)
unnamed: D14.2 (A), MX11.2 (ROW)
unnamed: D15.2 (A), MX12.2 (ROW)
unnamed: D16.2 (A), MX13.2 (ROW)
unnamed: D17.2 (A), MX14.2 (ROW)
unnamed: D18.2 (A), MX15.2 (ROW)
unnamed: D19.2 (A), MX16.2 (ROW)
unnamed: D20.2 (A), MX17.2 (ROW)
unnamed: D21.2 (A), MX18.2 (ROW)
unnamed: D22.2 (A), MX19.2 (ROW)
unnamed: D23.2 (A), MX20.2 (ROW)
unnamed: D24.2 (A), MX21.2 (ROW)
unnamed: D25.2 (A), MX22.2 (ROW)
unnamed: D26.2 (A), MX23.2 (ROW)
unnamed: D27.2 (A), MX24.2 (ROW)
unnamed: D28.2 (A), MX25.2 (ROW)
unnamed: D29.2 (A), MX26.2 (ROW)
unnamed: D30.2 (A), MX27.2 (ROW)
unnamed: D31.2 (A), MX28.2 (ROW)
unnamed: D32.2 (A), MX29.2 (ROW)
unnamed: D33.2 (A), MX30.2 (ROW)
unnamed: D34.2 (A), MX31.2 (ROW)
unnamed: D35.2 (A), MX32.2 (ROW)
unnamed: D36.2 (A), MX33.2 (ROW)
unnamed: D37.2 (A), MX34.2 (ROW)
unnamed: D38.2 (A), MX35.2 (ROW)
unnamed: D39.2 (A), MX36.2 (ROW)
unnamed: D40.2 (A), MX37.2 (ROW)
unnamed: D41.2 (A), MX38.2 (ROW)
unnamed: D42.2 (A), MX39.2 (ROW)
unnamed: D43.2 (A), MX40.2 (ROW)
unnamed: D44.2 (A), MX41.2 (ROW)
unnamed: D45.2 (A), MX42.2 (ROW)
unnamed: D46.2 (A), MX43.2 (ROW)
unnamed: D47.2 (A), MX44.2 (ROW)
unnamed: D48.2 (A), MX45.2 (ROW)
unnamed: D49.2 (A), MX46.2 (ROW)
unnamed: D50.2 (A), MX47.2 (ROW)
unnamed: D51.2 (A), MX48.2 (ROW)
unnamed: D52.2 (A), MX49.2 (ROW)
unnamed: D53.2 (A), MX50.2 (ROW)
unnamed: D54.2 (A), MX51.2 (ROW)
unnamed: D55.2 (A), MX52.2 (ROW)
unnamed: D56.2 (A), MX53.2 (ROW)
unnamed: D57.2 (A), MX54.2 (ROW)
unnamed: D58.2 (A), MX55.2 (ROW)
unnamed: D59.2 (A), MX56.2 (ROW)
unnamed: D60.2 (A), MX57.2 (ROW)
unnamed: D61.2 (A), MX58.2 (ROW)
unnamed: D62.2 (A), MX59.2 (ROW)
unnamed: D63.2 (A), MX60.2 (ROW)
unnamed: D64.2 (A), MX61.2 (ROW)
unnamed: D65.2 (A), MX62.2 (ROW)
unnamed: D66.2 (A), MX63.2 (ROW)
unnamed: D67.2 (A), MX64.2 (ROW)
unnamed: D68.2 (A), MX65.2 (ROW)
unnamed: D69.2 (A), MX66.2 (ROW)
unnamed: D70.2 (A), MX67.2 (ROW)
unnamed: D71.2 (A), MX68.2 (ROW)
unnamed: D72.2 (A), MX69.2 (ROW)
unnamed: D73.2 (A), MX70.2 (ROW)
unnamed: D74.2 (A), MX71.2 (ROW)
unnamed: D75.2 (A), MX72.2 (ROW)
unnamed: D76.2 (A), MX73.2 (ROW)
unnamed: D77.2 (A), MX74.2 (ROW)
unnamed: D78.2 (A), MX75.2 (ROW)
unnamed: D79.2 (A), MX76.2 (ROW)
unnamed: D80.2 (A), MX77.2 (ROW)
unnamed: D81.2 (A), MX78.2 (ROW)
unnamed: D82.2 (A), MX79.2 (ROW)
unnamed: D83.2 (A), MX80.2 (ROW)
unnamed: D84.2 (A), MX81.2 (ROW)
unnamed: D85.2 (A), MX82.2 (ROW)
unnamed: D86.2 (A), MX83.2 (ROW)
unnamed: D87.2 (A), MX84.2 (ROW)
unnamed: D88.2 (A), MX85.2 (ROW)
unnamed: D89.2 (A), MX86.2 (ROW)
unnamed: D90.2 (A), MX87.2 (ROW)
unnamed: D91.2 (A), MX88.2 (ROW)
unnamed: D92.2 (A), MX89.2 (ROW)
unnamed: D93.2 (A), MX90.2 (ROW)
unnamed: D94.2 (A), MX91.2 (ROW)
unnamed: D95.2 (A), MX92.2 (ROW)
unnamed: D96.2 (A), MX93.2 (ROW)
unnamed: D97.2 (A), MX94.2 (ROW)
unnamed: D98.2 (A), MX95.2 (ROW)
unnamed: D99.2 (A), MX96.2 (ROW)
unnamed: D100.2 (A), MX97.2 (ROW)
unnamed: D101.2 (A), MX98.2 (ROW)
unnamed: D102.2 (A), MX99.2 (ROW)
unnamed: D103.2 (A), MX100.2 (ROW)
unnamed: D104.2 (A), MX101.2 (ROW)
unnamed: D105.2 (A), MX102.2 (ROW)
unnamed: D106.2 (A), MX103.2 (ROW)
unnamed: D107.2 (A), MX104.2 (ROW)
unnamed: D108.2 (A), MX105.2 (ROW)

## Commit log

2023-04-02 start design of left PCB
    [left-pcb.kicad_pcb, left-pcb.kicad_sch]
2023-04-02 add external oscillators
    [left-pcb.kicad_sch]
2023-04-03 add switch matrix and JTAG port
    [left-pcb.kicad_sch, switch-matrix.kicad_sch]
2023-04-04 initial footprint assignments
    [left-pcb.kicad_sch, switch-matrix.kicad_sch]
2023-04-04 associate footprints
    [left-pcb.kicad_sch]
2023-04-05 switch layout
    [left-pcb.kicad_pcb, left-pcb.kicad_sch, switch-matrix.kicad_sch]
2023-04-06 left half layout
    [left-pcb.kicad_pcb, left-pcb.kicad_sch, switch-matrix.kicad_sch]
2023-04-07 bomb for the redesign
    [left-pcb.kicad_pcb, left-pcb.kicad_sch, split-kb.kicad_pcb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]
2023-04-07 layout complete
    [left_pcb.kicad_sch, left_switches.kicad_sch, right_pcb.kicad_sch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]
2023-05-02 begin redesign
    [left_pcb.kicad_sch, left_switches.kicad_sch, right_pcb.kicad_sch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]
2023-05-02 add custom footprint library to the project
    [left_pcb.kicad_sch, right_pcb.kicad_sch, split-kb.kicad_pcb]
2023-05-02 add flipped-stab footprints
2023-05-03 redesign complete
    [left_pcb.kicad_sch, left_switches.kicad_sch, right_pcb.kicad_sch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]
2023-05-03 v0.2 done
    [left_pcb.kicad_sch, left_switches.kicad_sch, right_pcb.kicad_sch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]
2023-05-18 start redesign for v0.3
    [left_pcb.kicad_sch, right_pcb.kicad_sch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]
2023-05-18 v0.3 routing done
    [left_pcb.kicad_sch, right_pcb.kicad_sch, split-kb.kicad_pcb]
2023-06-19 add more design files
    [combined baseplates v1.dxf, combined midplates v1.dxf, combined topplates v1.1 w_ feet.dxf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]
